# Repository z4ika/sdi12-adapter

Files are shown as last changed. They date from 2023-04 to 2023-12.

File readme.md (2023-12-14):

## SDI-12 to USB Type-B Adapter Board PCB
KiCAD project for an adapter powered by a common STM32G431 series microcontroller chip using the on-chip USB capabilities to communicate with a PC relying on VCOM CDC option, to allow for an easy communication.

Current revision includes bidirectional 5V - 3.3V level shifting without logical voltage level inversion. This ensures compability of SDI standard with TTL logic. All of the parts have been standarized and designated manufacturer is JLCPCB. Project includes index.html as BOM listing. 

## 3D renders
Front render
Back render

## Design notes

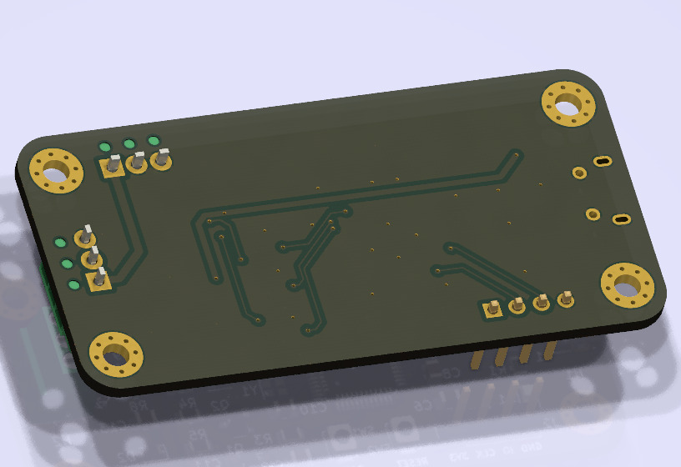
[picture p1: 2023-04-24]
back_3d.jpg

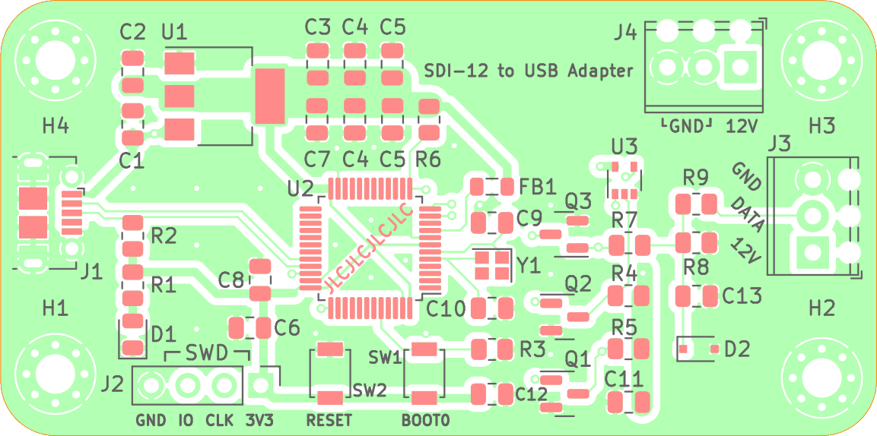
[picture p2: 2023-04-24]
front.png

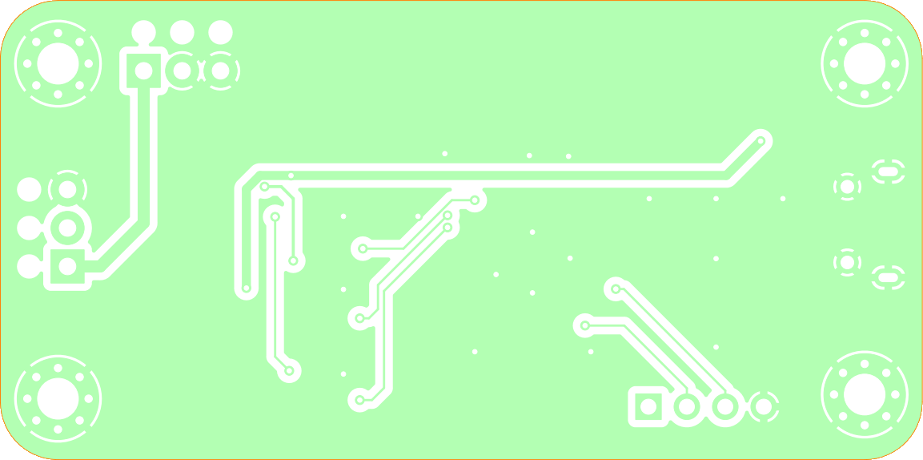
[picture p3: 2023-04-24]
back.png

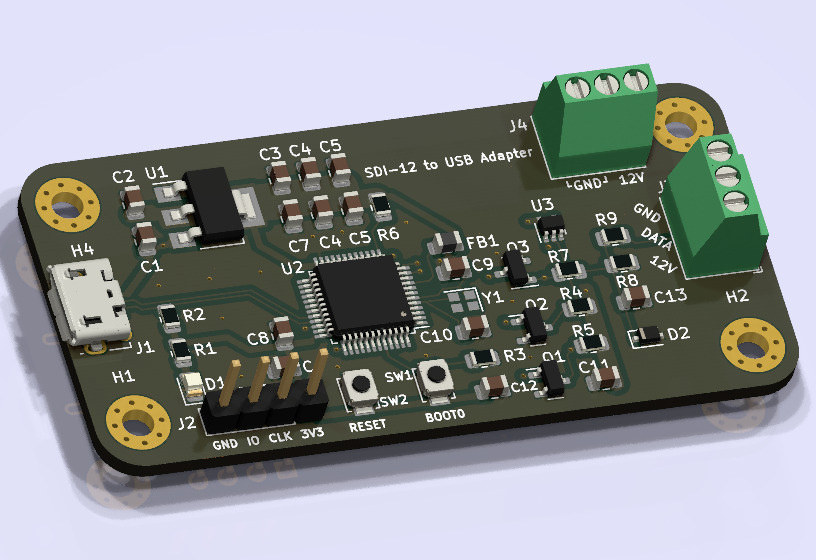
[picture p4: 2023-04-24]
front_3d.jpg

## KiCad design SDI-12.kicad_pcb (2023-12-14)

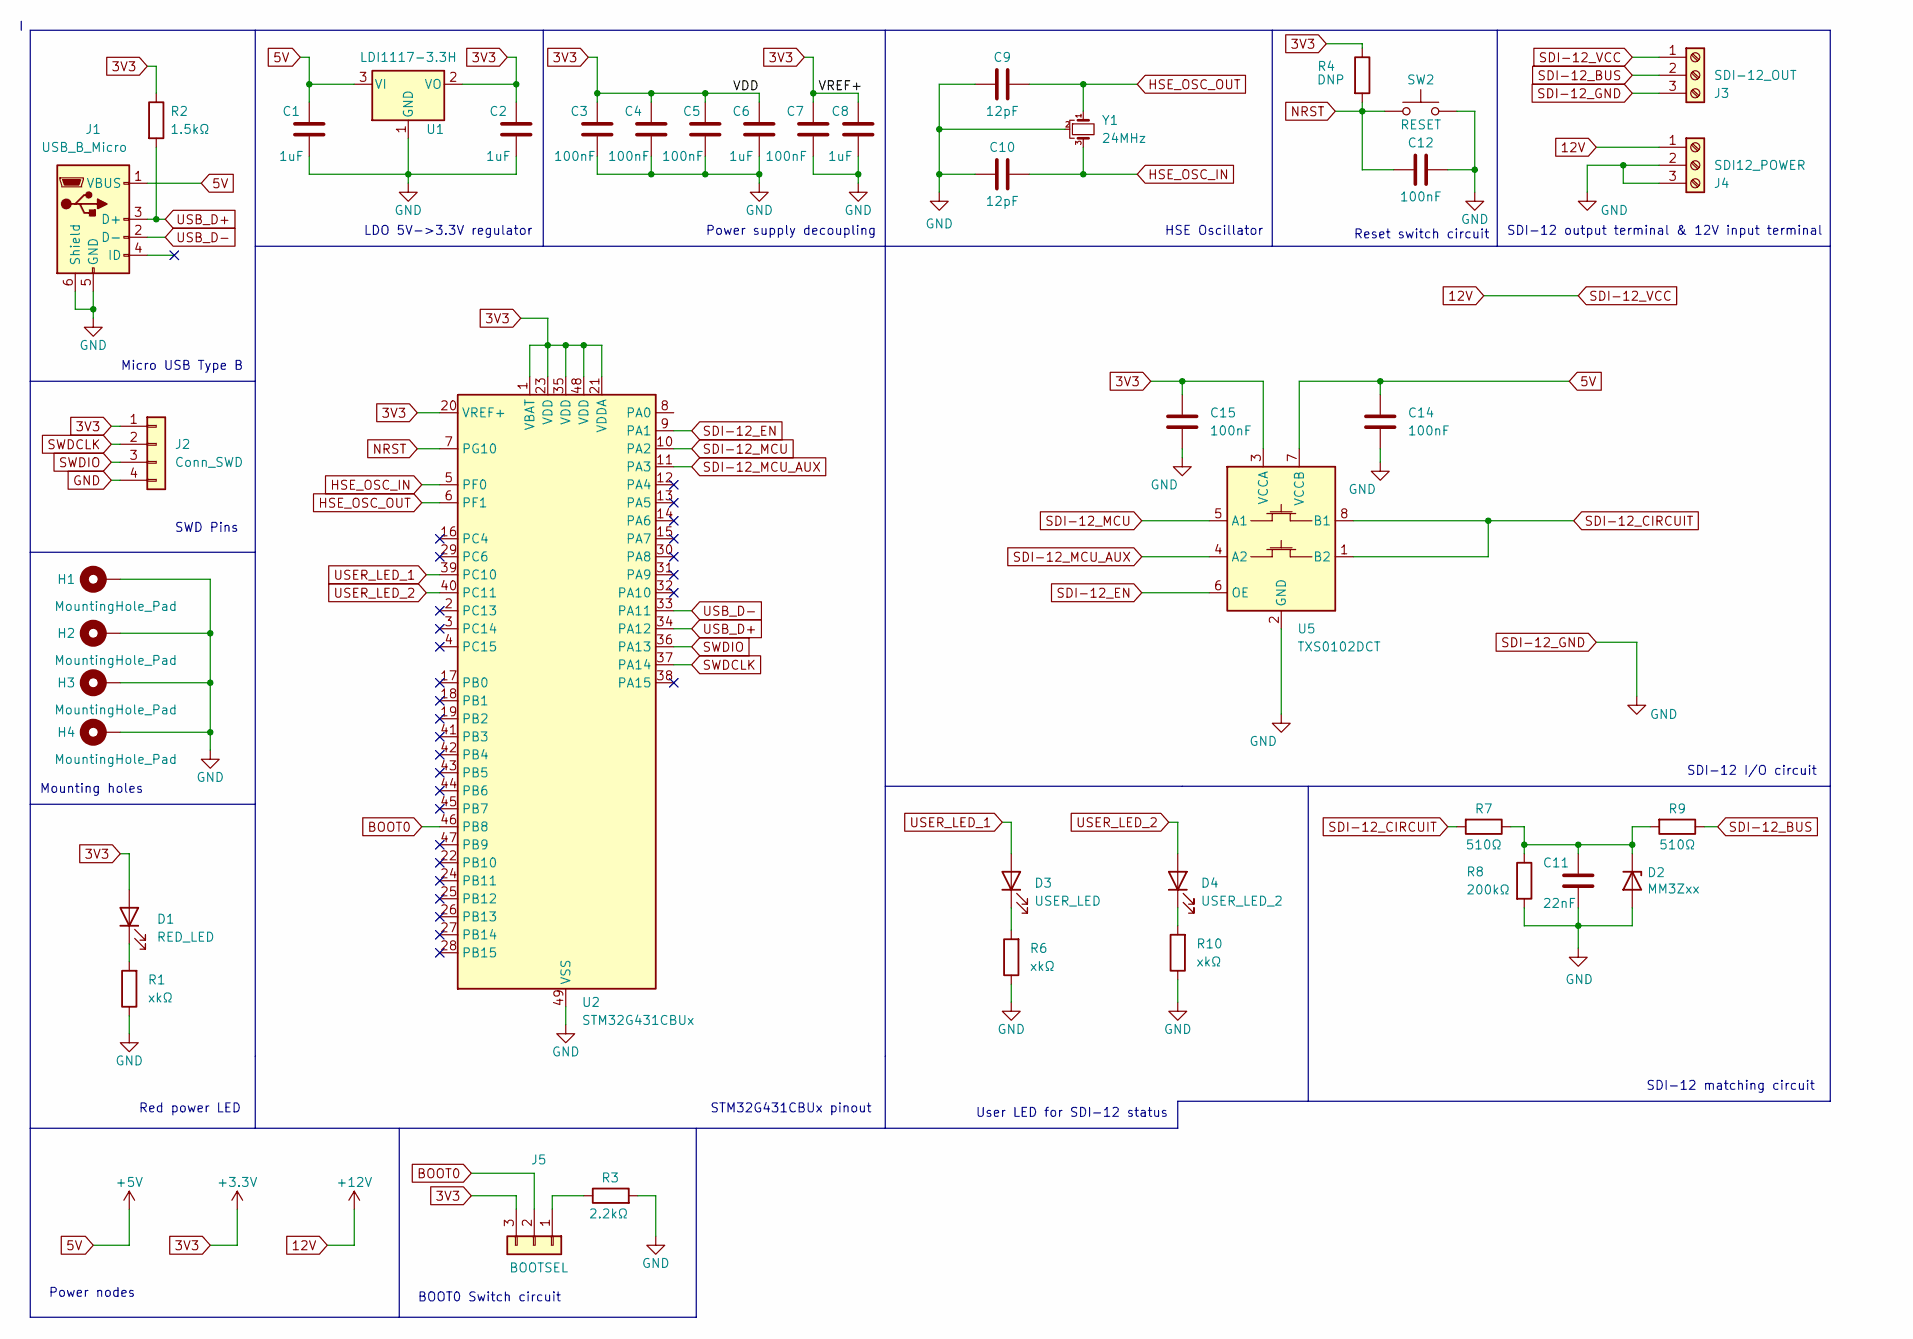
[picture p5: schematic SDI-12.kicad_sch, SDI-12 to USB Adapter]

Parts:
C1, C2, C6, C8: 1uF; C_0805_2012Metric
C3, C4, C5, C7, C12, C14, C15: 100nF; C_0603_1608Metric
C9, C10: 12pF; C_0603_1608Metric
C11: 22nF; C_0603_1608Metric
D1: RED_LED; LED_0805_2012Metric
D2: MM3Zxx; D_SOD-323F
D3: USER_LED; LED_0805_2012Metric
D4: USER_LED_2; LED_0805_2012Metric
H1, H2, H3, H4: MountingHole_Pad; MountingHole_2.7mm_Pad_Via
J1: USB_B_Micro; USB_Micro-B_Molex-105017-0001
J2: Conn_SWD; PinHeader_1x04_P2.54mm_Vertical
J3: SDI-12_OUT; TerminalBlock_Phoenix_MPT-0,5-3-2.54_1x03_P2.54mm_Horizontal
J4: SDI12_POWER; TerminalBlock_Phoenix_MPT-0,5-3-2.54_1x03_P2.54mm_Horizontal
J5: BOOTSEL; PinHeader_1x03_P2.54mm_Vertical
R1, R6, R10: xkΩ; R_0603_1608Metric
R2: 1.5kΩ; R_0603_1608Metric
R3: 2.2kΩ; R_0603_1608Metric
R4: DNP; R_0603_1608Metric
R7, R9: 510Ω; R_0603_1608Metric
R8: 200kΩ; R_0603_1608Metric
SW2: RESET; SW_SPST_B3U-1000P
U1: LDI1117-3.3H; SOT-223-3_TabPin2
U2: STM32G431CBUx; QFN-48-1EP_7x7mm_P0.5mm_EP5.6x5.6mm
U5: TXS0102DCT; SSOP-8_2.95x2.8mm_P0.65mm
Y1: 24MHz; Crystal_SMD_3225-4Pin_3.2x2.5mm

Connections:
3V3: C2.2, C3.2, C4.2, C5.2, C6.2, C7.2, C8.2, C15.1, D1.2 (A), J2.1, J5.3, R2.1, R4.1, U1.2 (VO), U2.1 (VBAT), U2.20 (VREF+), U2.21 (VDDA), U2.23 (VDD), U2.35 (VDD), U2.48 (VDD), U5.3 (VCCA)
5V: C1.2, C14.1, J1.1 (VBUS), U1.3 (VI), U5.7 (VCCB)
12V: J3.1, J4.1
BOOT0: J5.2, U2.46 (PB8)
GND: C1.1, C2.1, C3.1, C4.1, C5.1, C6.1, C7.1, C8.1, C9.1, C10.1, C11.2, C12.2, C14.2, C15.2, D2.2 (A), H1.1, H2.1, H3.1, H4.1, J1.5 (GND), J1.6 (Shield), J2.4, J3.3, J4.2, J4.3, R1.1, R3.2, R6.1, R8.2, R10.1, SW2.2, U1.1 (GND), U2.49 (VSS), U5.2 (GND), Y1.2
HSE_OSC_IN: C10.2, U2.5 (PF0), Y1.3
HSE_OSC_OUT: C9.2, U2.6 (PF1), Y1.1
NRST: C12.1, R4.2, SW2.1, U2.7 (PG10)
unnamed: D1.1 (K), R1.2
unnamed: C11.1, D2.1 (K), R7.1, R8.1, R9.2
unnamed: D3.1 (K), R6.2
unnamed: D4.1 (K), R10.2
unnamed: J5.1, R3.1
SDI-12_BUS: J3.2, R9.1
SDI-12_CIRCUIT: R7.2, U5.1 (B2), U5.8 (B1)
SDI-12_EN: U2.9 (PA1), U5.6 (OE)
SDI-12_MCU: U2.10 (PA2), U5.5 (A1)
SDI-12_MCU_AUX: U2.11 (PA3), U5.4 (A2)
SWDCLK: J2.2, U2.37 (PA14)
SWDIO: J2.3, U2.36 (PA13)
USB_D+: J1.3 (D+), R2.2, U2.34 (PA12)
USB_D-: J1.2 (D-), U2.33 (PA11)
USER_LED_1: D3.2 (A), U2.39 (PC10)
USER_LED_2: D4.2 (A), U2.40 (PC11)

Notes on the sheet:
SWD Pins
Red power LED
LDO 5V->3.3V regulator
Micro USB Type B
SDI-12 I/O circuit
STM32G431CBUx pinout
Reset switch circuit
SDI-12 matching circuit
Power nodes
SDI-12 output terminal & 12V input terminal
User LED for SDI-12 status
HSE Oscillator
Power supply decoupling
Mounting holes
BOOT0 Switch circuit

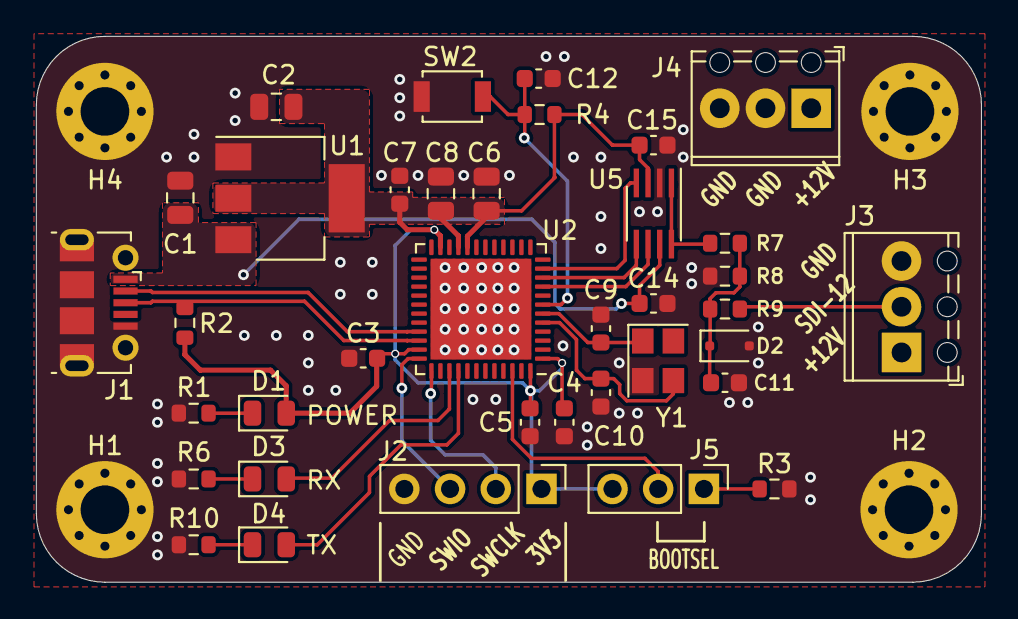
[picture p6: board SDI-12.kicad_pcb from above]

Board: 4 copper layers, 52.5 x 30.3 mm, 41 parts (0 on the bottom side), 24 nets.

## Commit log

2023-04-17 KiCAD 7.0 project & BOM website
    [SDI-12.kicad_pcb, SDI-12.kicad_sch, SDI-12.sch]
2023-04-24 - Crystal oscillator value changed to proper 16MHz - Minor font changes - Readme document - git lfs for readme graphics
    [SDI-12.kicad_pcb, SDI-12.kicad_sch]
2023-12-14 - STM32F103 replaced with G431 counterpart - TXS0102x for voltage level shifting - Added LED's for I/O status
    [SDI-12.kicad_pcb, SDI-12.kicad_sch]
